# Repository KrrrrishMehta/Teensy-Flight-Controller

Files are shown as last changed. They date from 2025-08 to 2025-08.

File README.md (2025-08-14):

# Agastya V1.0 - Quadcopter Flight Controller

Welcome to the repository for the **Agastya V1.0**, a custom-built quadcopter flight controller project by Team Phoenix. This project includes the complete firmware and details about the custom-designed Printed Circuit Board (PCB).

---

## 📋 Table of Contents

- [Overview](#-overview)
- [Hardware](#-hardware)
  - [Custom PCB: Agastya V1.0](#custom-pcb-agastya-v10)
  - [Components](#components)
- [Software & Firmware](#-software--firmware)
  - [Key Features](#key-features)
  - [Control System](#control-system)
- [Getting Started](#-getting-started)
  - [Prerequisites](#prerequisites)
  - [Setup & Flashing](#setup--flashing)
- [Flight & Tuning](#-flight--tuning)
  - [Pre-flight Checklist](#pre-flight-checklist)
  - [PID Tuning](#pid-tuning)
- [Contributing](#-contributing)

---

## 🚁 Overview

This project is a complete flight controller solution for a quadcopter. The firmware is written in C++ for the Arduino environment and is designed to run on a custom PCB, the "Agastya V1.0". The system reads data from an Inertial Measurement Unit (IMU), processes it through a Kalman filter, takes commands from an RC receiver, and uses a PID control loop to stabilize the drone and control its flight.

---

## 🔩 Hardware

### Custom PCB: Agastya V1.0

The heart of this project is a custom-designed PCB that integrates all the necessary components for a clean and reliable build.

[Agastya V1.0 PCB Layout]
*Assembly diagram for the Agastya V1.0 flight controller board.*

*PCB Assembly for the Agastya V1.0 flight controller board.*

### Components

- **Microcontroller:** An Arduino-compatible microcontroller (e.g., Teensy, Arduino Nano/Pro Mini).
- **IMU:** MPU-6050 Gyroscope & Accelerometer.
- **RC Receiver:** A receiver that outputs a PPM (Pulse Position Modulation) signal.
- **ESCs:** Four Electronic Speed Controllers for brushless motors.
- **Optional:** A barometer for altitude hold and a display for telemetry (connections are available on the PCB).

---

## 💻 Software & Firmware

The firmware is designed to be robust, efficient, and tunable. It's built on standard Arduino libraries for broad compatibility.

### Key Features

- **Sensor Fusion:** A 1D Kalman Filter is implemented to fuse noisy accelerometer data with drifty gyroscope data, providing a stable angle estimate for roll and pitch.
- **Gyro Calibration:** An automatic gyroscope calibration sequence runs at startup to cancel out sensor bias, ensuring stable flight.
- **PPM Receiver Support:** Reads up to 8 channels from a PPM RC receiver.
- **Fixed-Time Loop:** The main control loop runs at a consistent **250Hz (4ms)**, which is critical for stable PID performance.
- **Safety Features:**
  - **Arming Check:** The drone will not arm until a specific switch is activated on the transmitter.
  - **Throttle Cut-off:** When the throttle stick is at its lowest position, the motors are stopped, and the PID controllers are reset to prevent integral windup.

### Control System

The flight controller uses a cascaded PID control system. The current code is configured for **Rate (Acro) Mode**.

1.  **Rate PID Controller:** This is the inner loop that controls the drone's angular velocity (how fast it rotates). It takes the desired rotation rate from the pilot's sticks and works to match the drone's actual rotation rate (from the gyro) to that target.
2.  **Angle PID Controller (Level Mode):** *This loop is present in the code but is currently commented out.* When enabled, it forms the outer loop. It takes a desired angle from the pilot's sticks and calculates the necessary rotation rate to achieve that angle. This rate is then fed into the Rate PID controller.

---

## 🚀 Getting Started

### Prerequisites

1.  [Arduino IDE](https://www.arduino.cc/en/software)
2.  Required Libraries:
    - `<Wire.h>` (usually included with Arduino IDE)
    - `<Servo.h>` (usually included with Arduino IDE)
    - `<PulsePosition.h>` (Install via the Arduino Library Manager)
3.  Assembled Agastya V1.0 PCB or a breadboard equivalent.

### Setup & Flashing

1.  **Clone the Repository:**
    ```bash
    git clone [your-repository-url]
    ```
2.  **Open in Arduino IDE:** Open the `.ino` file in the Arduino IDE.
3.  **Select Board & Port:** Go to `Tools > Board` and select the microcontroller you are using. Then, select the correct COM port under `Tools > Port`.
4.  **Upload:** Click the "Upload" button to flash the firmware to the board.

---

## 🛠️ Flight & Tuning

**⚠️ WARNING: Always remove propellers before testing, calibrating, or flashing the flight controller.**

### Pre-flight Checklist

1.  Ensure the battery is fully charged.
2.  Place the drone on a perfectly level surface before powering on to ensure correct gyro calibration.
3.  Power on your transmitter first, then the drone.
4.  Check that the arming switch works as expected. The motors should not spin until armed.
5.  Perform a quick control check (without props) to ensure roll, pitch, and yaw respond correctly.

### PID Tuning

PID tuning is critical for stable, responsive flight. The gains are located at the top of the source code file.

```cpp
// --- RATE PID GAINS (Tuning Parameters) ---
float PRateRoll = 0.6;
float PRatePitch = PRateRoll;
float PRateYaw = 0;

float IRateRoll = 0.0;
float IRatePitch = IRateRoll;
float IRateYaw = 0;

float DRateRoll = 0.000;
float DRatePitch = DRateRoll;
float DRateYaw = 0;
```

- **P (Proportional):** This is the main gain. Increase it for a sharper, more responsive feel. If it's too high, the drone will oscillate rapidly.
- **I (Integral):** This gain corrects for drift and external forces like wind. Increase it to help the drone hold its angle. If it's too high, the drone will feel "sluggish" and may oscillate slowly.
- **D (Derivative):** This acts as a dampener. Increase it to smooth out the "kick" from the P-gain and reduce overshoot. If it's too high, the motors may get hot and you'll hear high-frequency noise.

**Tuning Process:**
1.  Start with I and D gains at zero.
2.  Increase the P-gain until you see fast oscillations, then back it off by about 20-30%.
3.  Increase the D-gain to smooth out the flight.
4.  Finally, slowly increase the I-gain to help the drone resist drift.

---

## 🤝 Contributing

Contributions are welcome! If you have improvements for the code or hardware, please feel free to fork this repository and submit a pull request.

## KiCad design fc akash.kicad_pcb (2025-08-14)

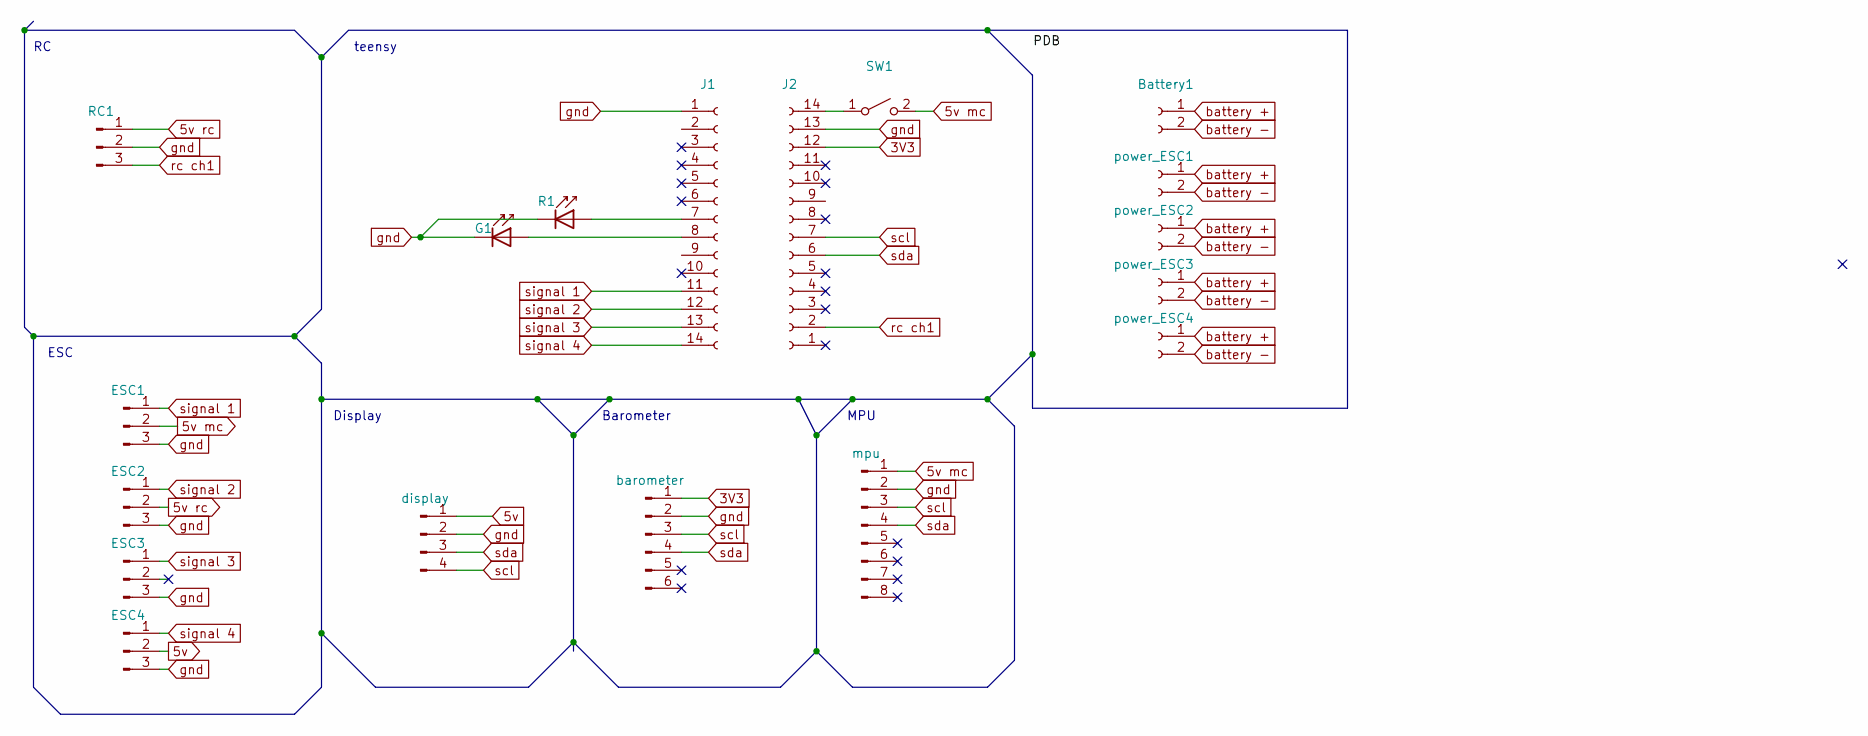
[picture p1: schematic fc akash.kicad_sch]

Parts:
Battery1: Conn_01x02_Socket; SolderWire-0.25sqmm_1x02_P4.5mm_D0.65mm_OD2mm
ESC1, ESC2, ESC3, ESC4: Conn_01x03_Pin; PinHeader_1x03_P2.54mm_Vertical
G1: SFH482; LED_D5.0mm_FlatTop
J1, J2: Conn_01x14_Socket; PinHeader_1x14_P2.54mm_Vertical
J3: mpu; PinHeader_1x08_P2.54mm_Vertical
J5: barometer; PinHeader_1x06_P2.54mm_Vertical
J6: display; PinHeader_1x04_P2.54mm_Vertical
R1: SFH482; LED_D5.0mm_FlatTop
RC1: Conn_01x03_Pin; PinHeader_1x03_P2.54mm_Vertical
SW1: SW_SPST; PinSocket_1x03_P2.54mm_Vertical
power_ESC1, power_ESC2, power_ESC3, power_ESC4: Conn_01x02_Socket; battery connector banana

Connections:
3V3: J2.12, J5.1
5v: ESC4.2, J6.1
5v mc: ESC1.2, J3.1, SW1.2 (B)
5v rc: ESC2.2, RC1.1
unnamed: G1.2 (A), J1.8
unnamed: J1.7, R1.2 (A)
unnamed: J2.14, SW1.1 (A)
battery +: Battery1.1, power_ESC1.1, power_ESC2.1, power_ESC3.1, power_ESC4.1
battery -: Battery1.2, power_ESC1.2, power_ESC2.2, power_ESC3.2, power_ESC4.2
gnd: ESC1.3, ESC2.3, ESC3.3, ESC4.3, G1.1 (K), J1.1, J2.13, J3.2, J5.2, J6.2, R1.1 (K), RC1.2
rc ch1: J2.2, RC1.3
scl: J2.7, J3.3, J5.3, J6.4
sda: J2.6, J3.4, J5.4, J6.3
signal 1: ESC1.1, J1.11
signal 2: ESC2.1, J1.12
signal 3: ESC3.1, J1.13
signal 4: ESC4.1, J1.14

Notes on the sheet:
ESC
MPU
teensy
Barometer
Display

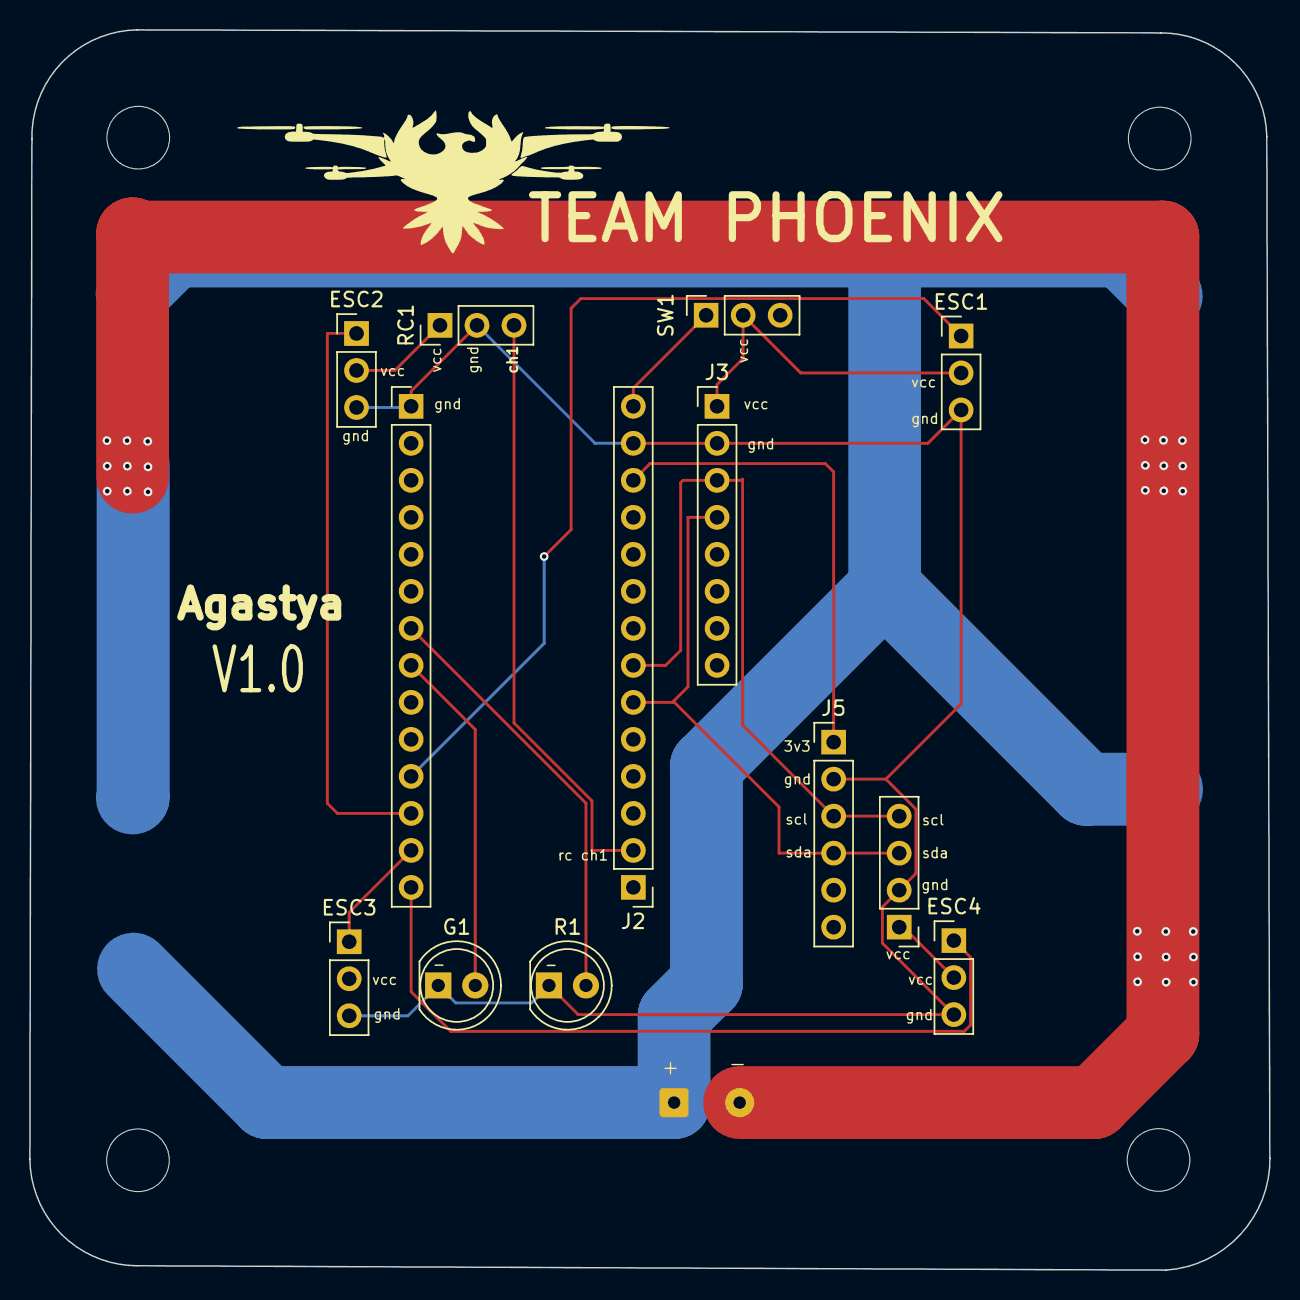
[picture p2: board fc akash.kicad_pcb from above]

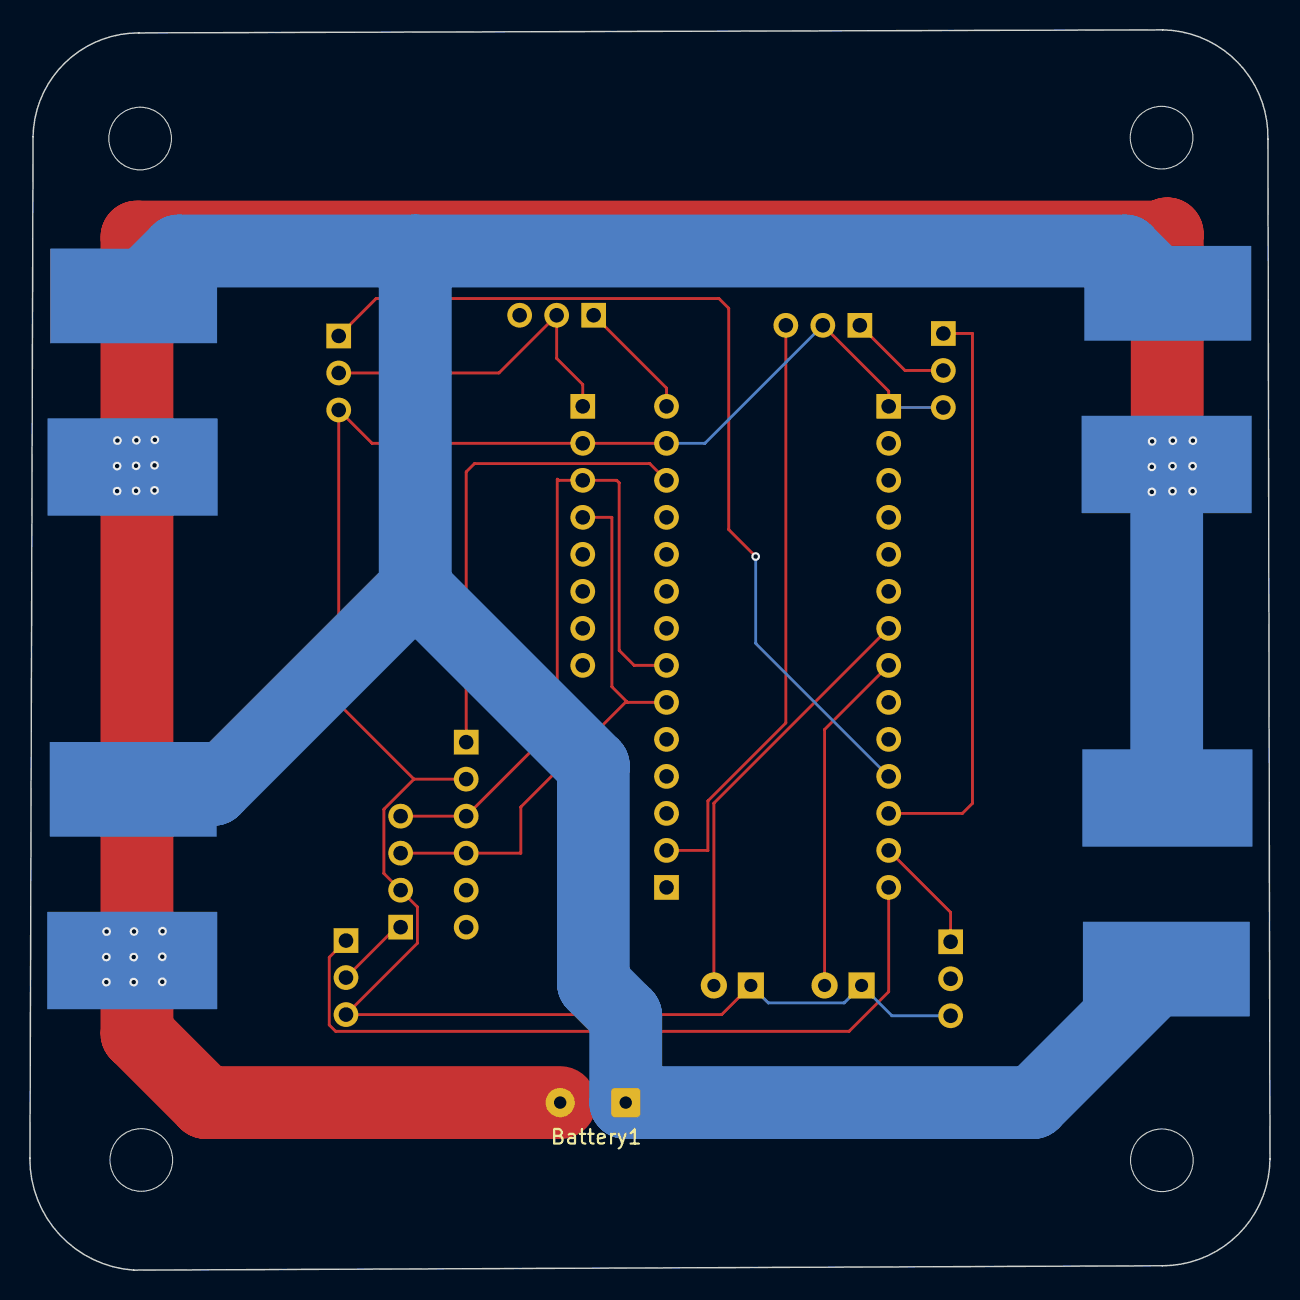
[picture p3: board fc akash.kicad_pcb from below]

Board: 2 copper layers, 85.1 x 85.1 mm, 18 parts (5 on the bottom side), 17 nets.

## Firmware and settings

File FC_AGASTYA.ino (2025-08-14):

//================================================================================================================//
//                                         INCLUDE LIBRARIES                                                      //
//================================================================================================================//
#include <Wire.h>             // I2C communication library for talking to sensors like the MPU-6050
#include <PulsePosition.h>    // Library to read PPM signals from an RC receiver
#include <Servo.h>            // Library to control ESCs (Electronic Speed Controllers) like servos

//================================================================================================================//
//                                        GYROSCOPE VARIABLES                                                     //
//================================================================================================================//
float RateRoll, RatePitch, RateYaw;                               // Current angular rates from the gyro (degrees/second)
float RateCalibrationRoll, RateCalibrationPitch, RateCalibrationYaw; // Calibration offsets for the gyro
int RateCalibrationNumber;                                        // Counter for the calibration loop

//================================================================================================================//
//                                        RECEIVER & MOTOR VARIABLES                                              //
//================================================================================================================//
Servo esc1, esc2, esc3, esc4;                                     // Servo objects for the four ESCs/motors
PulsePositionInput ReceiverInput(RISING);                         // Object to handle PPM input from the RC receiver
float ReceiverValue[] = {0, 0, 0, 0, 0, 0, 0, 0};                 // Array to store the pulse widths for each receiver channel
int ChannelNumber = 0;                                            // Number of channels detected from the receiver

//================================================================================================================//
//                                        FLIGHT & SYSTEM VARIABLES                                               //
//================================================================================================================//
float Voltage, Current;                   // Battery voltage and current draw
uint32_t LoopTimer;                       // Timer to ensure the main loop runs at a consistent rate (e.g., 250Hz)
float InputRoll, InputThrottle, InputPitch, InputYaw; // Processed inputs from the PID controllers
float MotorInput1, MotorInput2, MotorInput3, MotorInput4; // Final pulse width values sent to the ESCs

//================================================================================================================//
//                                        PID CONTROLLER VARIABLES (RATE MODE)                                    //
//================================================================================================================//
// Desired rates are the target angular velocities, typically set by the pilot's sticks (in acro/rate mode)
// or by the angle PID controller (in self-level mode).
float DesiredRateRoll, DesiredRatePitch, DesiredRateYaw;

// Error is the difference between the desired rate and the actual rate from the gyro.
float ErrorRateRoll, ErrorRatePitch, ErrorRateYaw;

// Previous errors and I-term accumulations are stored for the next PID calculation.
float PrevErrorRateRoll, PrevErrorRatePitch, PrevErrorRateYaw;
float PrevItermRateRoll, PrevItermRatePitch, PrevItermRateYaw;

// The PID controller's output is stored in this array.
float PIDReturn[] = {0, 0, 0};

// --- RATE PID GAINS (Tuning Parameters) ---
// These values determine how the drone reacts to control inputs and disturbances.
// P (Proportional): Reacts to the current error. Higher P = sharper response.
float PRateRoll = 0.6;
float PRatePitch = PRateRoll; // Pitch P-gain is often the same as Roll
float PRateYaw = 0;           // Yaw is often less responsive and needs different tuning.

// I (Integral): Corrects for steady-state error over time. Helps resist drift.
float IRateRoll = 0.0;
float IRatePitch = IRateRoll;
float IRateYaw = 0;

// D (Derivative): Dampens the response by reacting to the rate of change of the error. Reduces overshoot.
float DRateRoll = 0.000;
float DRatePitch = DRateRoll;
float DRateYaw = 0;

//================================================================================================================//
//                                     ACCELEROMETER & KALMAN FILTER VARIABLES                                    //
//================================================================================================================//
// Raw accelerometer data and calculated angles
float AccX, AccY, AccZ;
float AngleRoll, AnglePitch;

// Kalman filter variables for Roll axis
float KalmanAngleRoll = 0;
float KalmanUncertaintyAngleRoll = 2 * 2;

// Kalman filter variables for Pitch axis
float KalmanAnglePitch = 0;
float KalmanUncertaintyAnglePitch = 2 * 2;

// Output array for the Kalman filter function
float Kalman1DOutput[] = {0, 0};

//================================================================================================================//
//                                        PID CONTROLLER VARIABLES (ANGLE/LEVEL MODE)                             //
//================================================================================================================//
// Desired angles are the target orientation of the drone, set by the pilot's sticks.
float DesiredAngleRoll, DesiredAnglePitch;

// Error is the difference between the desired angle and the actual (Kalman filtered) angle.
float ErrorAngleRoll, ErrorAnglePitch;

// Previous errors and I-term accumulations for the angle PID controller.
float PrevErrorAngleRoll, PrevErrorAnglePitch;
float PrevItermAngleRoll, PrevItermAnglePitch;

// --- ANGLE PID GAINS (Tuning Parameters for Self-Leveling) ---
float PAngleRoll = 2.8;
float PAnglePitch = 3.0;
float IAngleRoll = 0.1;
float IAnglePitch = 0.1;
float DAngleRoll = 0.001;
float DAnglePitch = 0.001;


//================================================================================================================//
//                                        KALMAN FILTER FUNCTION                                                  //
//================================complements the accelerometer and gyroscope data to get a more stable angle estimate.
// It fuses the noisy but drift-free accelerometer angle with the clean but drifty gyroscope rate.
void kalman_1d(float KalmanState, float KalmanUncertainty, float KalmanInput, float KalmanMeasurement) {
  // Prediction stage: estimate the current state based on the previous state and the gyro input.
  KalmanState = KalmanState + 0.004 * KalmanInput; // 0.004 is the loop time (4ms)
  KalmanUncertainty = KalmanUncertainty + 0.004 * 0.004 * 4 * 4;

  // Update stage: correct the predicted state with the new measurement from the accelerometer.
  float KalmanGain = KalmanUncertainty * 1 / (1 * KalmanUncertainty + 3 * 3);
  KalmanState = KalmanState + KalmanGain * (KalmanMeasurement - KalmanState);
  KalmanUncertainty = (1 - KalmanGain) * KalmanUncertainty;

  // Store the results.
  Kalman1DOutput[0] = KalmanState;
  Kalman1DOutput[1] = KalmanUncertainty;
}

//================================================================================================================//
//                                        BATTERY MONITORING FUNCTION                                             //
//================================================================================================================//
// Reads analog pins to measure battery voltage and current.
void battery_voltage(void) {
  Voltage = (float)analogRead(15) / 62; // Read pin A15 and convert to voltage
  Current = (float)analogRead(21) * 0.089; // Read pin A21 and convert to current
}

//================================================================================================================//
//                                        RECEIVER READING FUNCTION                                               //
//================================================================================================================//
// Checks for and reads new data from the RC receiver.
void read_receiver(void) {
  ChannelNumber = ReceiverInput.available(); // Check if new channel data is available
  if (ChannelNumber > 0) {
    // Loop through all available channels and store their pulse width values.
    for (int i = 1; i <= ChannelNumber; i++) {
      ReceiverValue[i - 1] = ReceiverInput.read(i);
    }
  }
}

//================================================================================================================//
//                                        IMU (GYRO/ACCEL) READING FUNCTION                                       //
//================================================================================================================//
// Communicates with the MPU-6050 Inertial Measurement Unit (IMU) to get sensor data.
void gyro_signals(void) {
  // --- Configure and Read Accelerometer ---
  Wire.beginTransmission(0x68); // Start I2C communication with the MPU-6050 (address 0x68)
  Wire.write(0x1A);             // Access DLPF (Digital Low Pass Filter) register
  Wire.write(0x05);             // Set the DLPF to a low setting
  Wire.endTransmission();
  Wire.beginTransmission(0x68);
  Wire.write(0x1C);             // Access accelerometer configuration register
  Wire.write(0x10);             // Set accelerometer sensitivity to +/- 8g
  Wire.endTransmission();
  Wire.beginTransmission(0x68);
  Wire.write(0x3B);             // Set the starting register for accelerometer data
  Wire.endTransmission();
  Wire.requestFrom(0x68, 6);    // Request 6 bytes of data (X, Y, Z, high & low bytes)
  int16_t AccXLSB = Wire.read() << 8 | Wire.read(); // Combine bytes for X-axis
  int16_t AccYLSB = Wire.read() << 8 | Wire.read(); // Combine bytes for Y-axis
  int16_t AccZLSB = Wire.read() << 8 | Wire.read(); // Combine bytes for Z-axis

  // --- Configure and Read Gyroscope ---
  Wire.beginTransmission(0x68);
  Wire.write(0x1B);             // Access gyroscope configuration register
  Wire.write(0x8);              // Set gyroscope sensitivity to +/- 500 degrees/sec
  Wire.endTransmission();
  Wire.beginTransmission(0x68);
  Wire.write(0x43);             // Set the starting register for gyro data
  Wire.endTransmission();
  Wire.requestFrom(0x68, 6);    // Request 6 bytes of data
  int16_t GyroX = Wire.read() << 8 | Wire.read(); // Combine bytes for X-axis (Roll)
  int16_t GyroY = Wire.read() << 8 | Wire.read(); // Combine bytes for Y-axis (Pitch)
  int16_t GyroZ = Wire.read() << 8 | Wire.read(); // Combine bytes for Z-axis (Yaw)

  // --- Convert Raw Sensor Data to Usable Units ---
  // Convert raw gyro data to degrees/second
  RateRoll = (float)GyroX / 65.5;
  RatePitch = (float)GyroY / 65.5;
  RateYaw = (float)GyroZ / 65.5;

  // Convert raw accelerometer data to g's and apply calibration offsets
  AccX = (float)AccXLSB / 4096 - 0.05;
  AccY = (float)AccYLSB / 4096 + 0.06;
  AccZ = (float)AccZLSB / 4096 + 0.13;

  // Calculate roll and pitch angles from accelerometer data (in degrees)
  // This is noisy and only accurate when the drone is not accelerating.
  AngleRoll = atan(AccY / sqrt(AccX * AccX + AccZ * AccZ)) * 1 / (3.142 / 180);
  AnglePitch = -atan(AccX / sqrt(AccY * AccY + AccZ * AccZ)) * 1 / (3.142 / 180);
}


//================================================================================================================//
//                                        PID CALCULATION FUNCTION                                                //
//================================================================================================================//
// This function calculates the output of a PID controller for a given axis.
void pid_equation(float Error, float P, float I, float D, float PrevError, float PrevIterm) {
  // Proportional term
  float Pterm = P * Error;

  // Integral term with anti-windup (trapezoidal integration)
  float Iterm = PrevIterm + I * (Error + PrevError) * 0.004 / 2;
  if (Iterm > 400) Iterm = 400;       // Clamp the I-term to prevent integral windup
  else if (Iterm < -400) Iterm = -400;

  // Derivative term
  float Dterm = D * (Error - PrevError) / 0.004;

  // Sum the terms to get the final PID output
  float PIDOutput = Pterm + Iterm + Dterm;
  if (PIDOutput > 400) PIDOutput = 400; // Clamp the total output
  else if (PIDOutput < -400) PIDOutput = -400;

  // Store the results for use in the main loop and for the next iteration
  PIDReturn[0] = PIDOutput;
  PIDReturn[1] = Error; // The current error becomes the previous error for the next loop
  PIDReturn[2] = Iterm; // The current I-term becomes the previous I-term
}

//================================================================================================================//
//                                        PID RESET FUNCTION                                                      //
//================================================================================================================//
// Resets the PID controller's state variables. This is crucial when disarming
// to prevent the I-term from accumulating and causing a lurch on re-arming.
void reset_pid(void) {
  PrevErrorRateRoll = 0; PrevErrorRatePitch = 0; PrevErrorRateYaw = 0;
  PrevItermRateRoll = 0; PrevItermRatePitch = 0; PrevItermRateYaw = 0;
  PrevErrorAngleRoll = 0; PrevErrorAnglePitch = 0;
  PrevItermAngleRoll = 0; PrevItermAnglePitch = 0;
}
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
void loop() {
  // --- SENSOR FUSION ---
  gyro_signals(); // Get the latest data from the MPU-6050

  // Apply the calibration offsets to the raw gyro rates.
  RateRoll -= RateCalibrationRoll;
  RatePitch -= RateCalibrationPitch;
  RateYaw -= RateCalibrationYaw;

  // Run the Kalman filter to get a stable angle estimate for roll and pitch.
  kalman_1d(KalmanAngleRoll, KalmanUncertaintyAngleRoll, RateRoll, AngleRoll);
  KalmanAngleRoll = Kalman1DOutput[0];
  KalmanUncertaintyAngleRoll = Kalman1DOutput[1];

  kalman_1d(KalmanAnglePitch, KalmanUncertaintyAnglePitch, RatePitch, AnglePitch);
  KalmanAnglePitch = Kalman1DOutput[0];
  KalmanUncertaintyAnglePitch = Kalman1DOutput[1];

  // --- READ CONTROLLER INPUTS ---
  read_receiver(); // Get the latest commands from the pilot.

  // Convert receiver pulse widths (typically 1000-2000) into desired angles/rates.
  // These lines are for self-leveling mode.
  DesiredAngleRoll = 0.09 * (ReceiverValue[0] - 1500);  // Channel 1 for Roll
  DesiredAnglePitch = 0.09 * (ReceiverValue[1] - 1500); // Channel 2 for Pitch
  InputThrottle = ReceiverValue[2];                      // Channel 3 for Throttle
  DesiredRateYaw = 0.15 * (ReceiverValue[3] - 1500);   // Channel 4 for Yaw Rate

  // --- PID CONTROLLER CALCULATIONS ---
  // ** This code is configured for RATE (ACRO) MODE. **
  // The angle PID controller is commented out. In this mode, the pilot directly controls
  // the drone's rate of rotation, not its angle.

  // // ANGLE MODE PID (Currently commented out)
  // // First, calculate the error between the desired angle and the actual angle.
  // ErrorAngleRoll = DesiredAngleRoll - KalmanAngleRoll;
  // ErrorAnglePitch = DesiredAnglePitch - KalmanAnglePitch;
  // // The output of the angle PID controller becomes the *input* (the desired rate) for the rate PID controller.
  // pid_equation(ErrorAngleRoll, PAngleRoll, IAngleRoll, DAngleRoll, PrevErrorAngleRoll, PrevItermAngleRoll);
  // DesiredRateRoll = PIDReturn[0];
  // PrevErrorAngleRoll = PIDReturn[1];
  // PrevItermAngleRoll = PIDReturn[2];
  // pid_equation(ErrorAnglePitch, PAnglePitch, IAnglePitch, DAnglePitch, PrevErrorAnglePitch, PrevItermAnglePitch);
  // DesiredRatePitch = PIDReturn[0];
  // PrevErrorAnglePitch = PIDReturn[1];
  // PrevItermAnglePitch = PIDReturn[2];


  // RATE MODE PID
  // Calculate the error between the desired rate and the actual rate from the gyro.
  // In pure rate mode, DesiredRateRoll and DesiredRatePitch would be set directly from the receiver,
  // but here they are implicitly 0 because the angle controller is off.
  ErrorRateRoll = DesiredRateRoll - RateRoll;
  ErrorRatePitch = DesiredRatePitch - RatePitch;
  ErrorRateYaw = DesiredRateYaw - RateYaw;

  // Calculate the PID output for each axis.
  pid_equation(ErrorRateRoll, PRateRoll, IRateRoll, DRateRoll, PrevErrorRateRoll, PrevItermRateRoll);
  InputRoll = PIDReturn[0];
  PrevErrorRateRoll = PIDReturn[1];
  PrevItermRateRoll = PIDReturn[2];

  pid_equation(ErrorRatePitch, PRatePitch, IRatePitch, DRatePitch, PrevErrorRatePitch, PrevItermRatePitch);
  InputPitch = PIDReturn[0];
  PrevErrorRatePitch = PIDReturn[1];
  PrevItermRatePitch = PIDReturn[2];

  pid_equation(ErrorRateYaw, PRateYaw, IRateYaw, DRateYaw, PrevErrorRateYaw, PrevItermRateYaw);
  InputYaw = PIDReturn[0];
  PrevErrorRateYaw = PIDReturn[1];
  PrevItermRateYaw = PIDReturn[2];

  // --- MOTOR MIXING ---
  // Mix the throttle and PID outputs to determine the speed for each of the four motors.
  // This is for a standard "X" quadcopter configuration.
  if (InputThrottle > 1800) InputThrottle = 1800; // Limit max throttle

  MotorInput1 = InputThrottle - InputRoll - InputPitch - InputYaw; // Front-Right
  MotorInput2 = InputThrottle - InputRoll + InputPitch + InputYaw; // Rear-Right
  MotorInput3 = InputThrottle + InputRoll + InputPitch - InputYaw; // Front-Left
  MotorInput4 = InputThrottle + InputRoll - InputPitch + InputYaw; // Rear-Left

  // Limit the motor outputs to the valid range for the ESCs (e.g., 1000-2000 microseconds).
  if (MotorInput1 > 2000) MotorInput1 = 1999;
  if (MotorInput2 > 2000) MotorInput2 = 1999;
  if (MotorInput3 > 2000) MotorInput3 = 1999;
  if (MotorInput4 > 2000) MotorInput4 = 1999;

  int ThrottleIdle = 1180; // Minimum throttle to keep motors spinning
  if (MotorInput1 < ThrottleIdle) MotorInput1 = ThrottleIdle;
  if (MotorInput2 < ThrottleIdle) MotorInput2 = ThrottleIdle;
  if (MotorInput3 < ThrottleIdle) MotorInput3 = ThrottleIdle;
  if (MotorInput4 < ThrottleIdle) MotorInput4 = ThrottleIdle;

  // --- THROTTLE CUT-OFF / DISARM ---
  // If the throttle stick is all the way down, cut power to the motors and reset the PIDs.
  int ThrottleCutOff = 900;
  if (ReceiverValue[2] < 1050) {
    MotorInput1 = ThrottleCutOff;
    MotorInput2 = ThrottleCutOff;
    MotorInput3 = ThrottleCutOff;
    MotorInput4 = ThrottleCutOff;
    reset_pid(); // Reset PID integrals to prevent issues on re-arming
  }

  // --- WRITE TO MOTORS ---
  // Send the final calculated pulse width signals to the ESCs.
  esc1.writeMicroseconds(MotorInput1);
  esc2.writeMicroseconds(MotorInput2);
  esc3.writeMicroseconds(MotorInput3);
  esc4.writeMicroseconds(MotorInput4);

  // --- DEBUGGING OUTPUT (Optional) ---
  // Print motor values and rates to the serial monitor for tuning and debugging.
  // Serial.print("1: ");
  // Serial.print(MotorInput1);
  // Serial.print("2: ");
  // Serial.print(MotorInput2);
  // Serial.print("3: ");
  // Serial.print(MotorInput3);
  // Serial.print("4: ");
  // Serial.println(MotorInput4);
  // Serial.print("x: ");
  // Serial.print(RateRoll);
  // Serial.print("y: ");
  // Serial.print(RatePitch);
  // Serial.print("z: ");
  // Serial.println(RateYaw);

  // --- LOOP TIMING ---
  // Wait until 4000 microseconds (4ms) have passed since the start of the loop.
  // This ensures the loop runs at a consistent 250Hz, which is important for stable PID control.
  while (micros() - LoopTimer < 4000);
  LoopTimer = micros(); // Reset the timer for the next loop iteration.
}
